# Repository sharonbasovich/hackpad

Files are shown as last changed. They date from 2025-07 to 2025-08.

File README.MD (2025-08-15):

# Sharon's Hackpad
This is a macropad that I made for HackClub's Highway program.

## Features
- 16 Switches (4x4 Matrix)
- 16 Neopixels
- An OLED Screen

## Hackpad


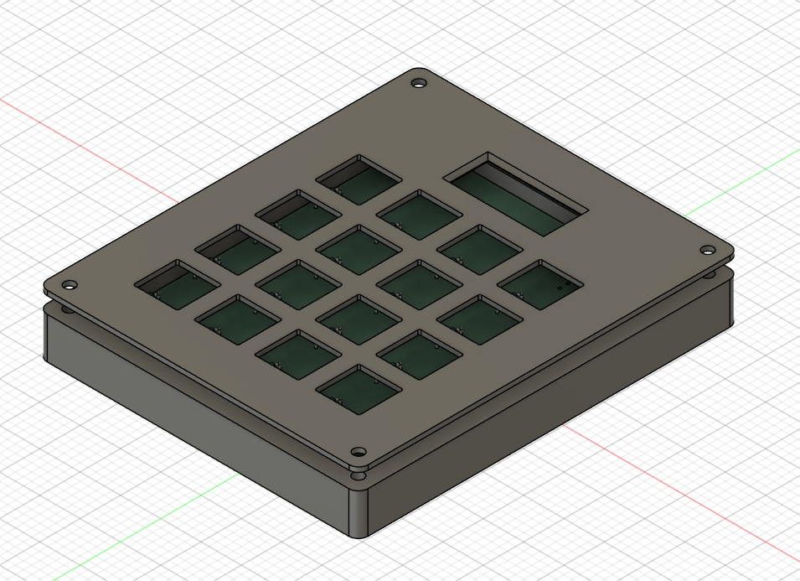
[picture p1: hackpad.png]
Hackpad


## Schematic
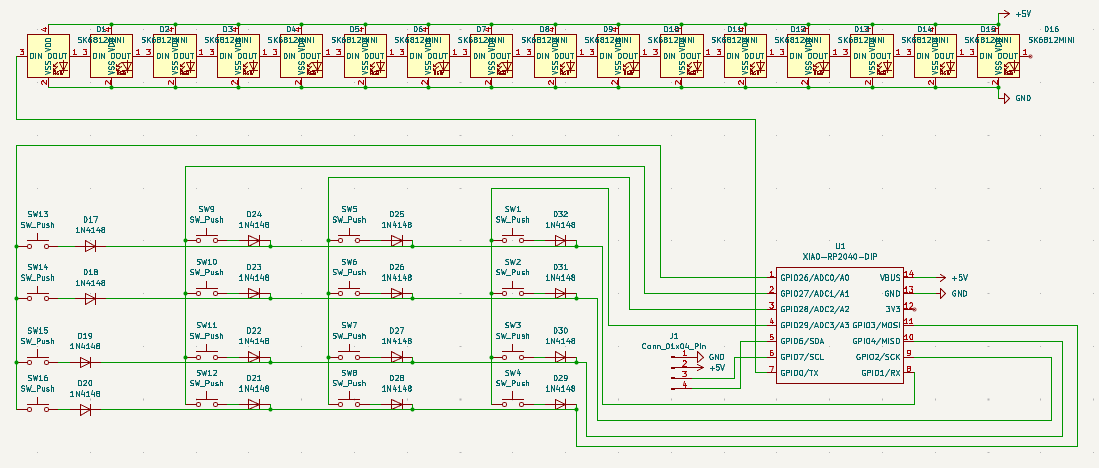
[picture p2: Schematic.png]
Schematic

## PCB
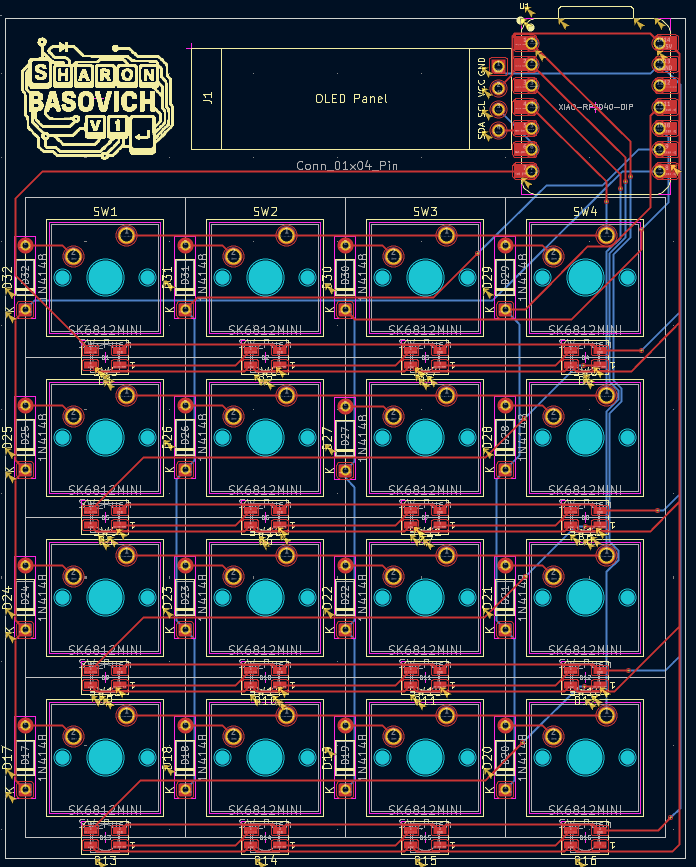
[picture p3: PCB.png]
PCB

## Case
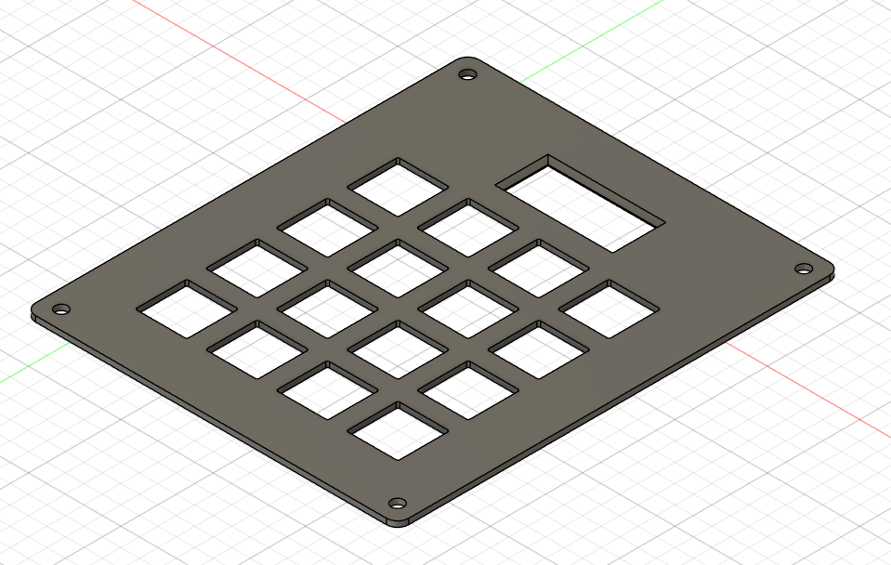
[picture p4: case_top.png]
Case Top

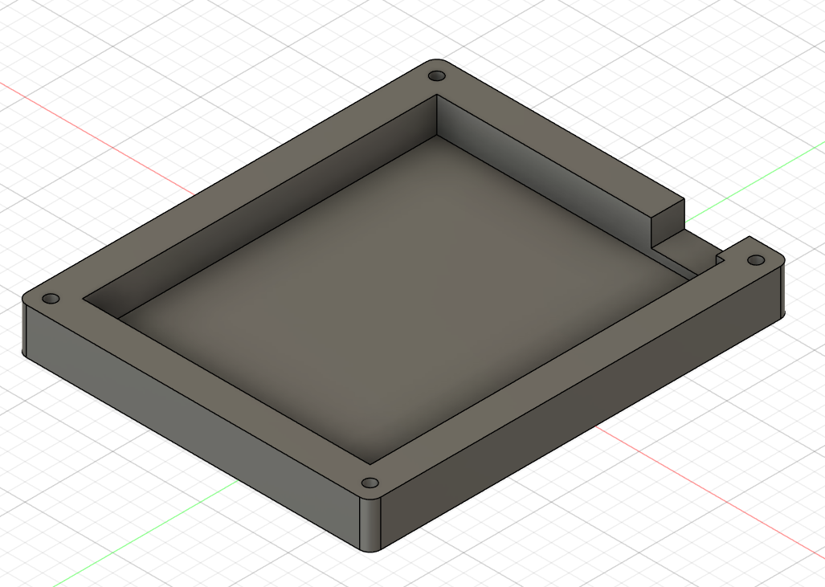
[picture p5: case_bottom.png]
Case Bottom


## BOM
- 16x Cherry MX Switches
- 16x DSA Keycaps
- 16x 1N4148 Diodes
- 1x 0.91" 128x32 OLED Display
- 1x XIAO RP2040
- 1x Case Bottom Piece
- 1x Case Top Piece
- 4x M3x16mm Screws
- 4x M3x5mx4mm Heatset Inserts

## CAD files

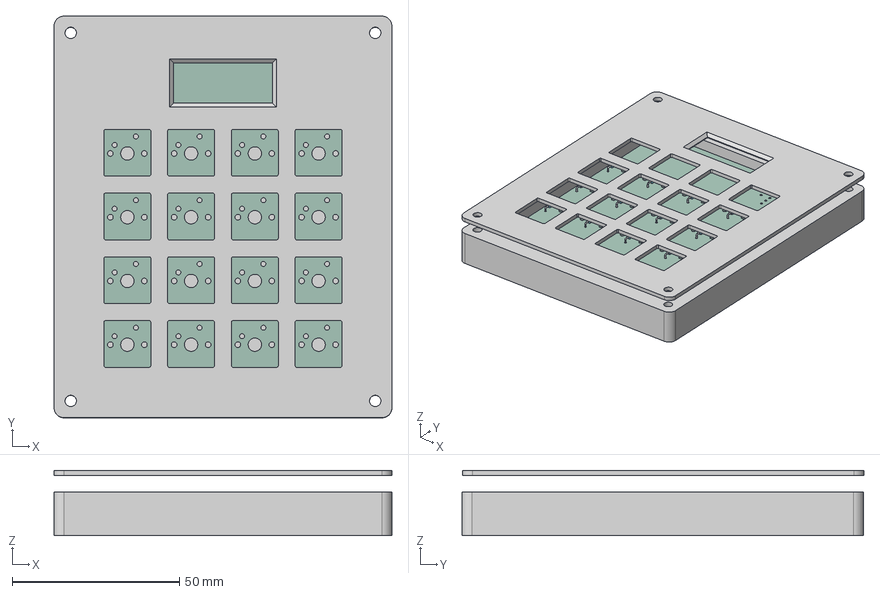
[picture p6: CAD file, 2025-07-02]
CAD/hackpad_assembly.step
101.0 x 120.1 x 19.5 mm
D_DO-35_SOD27_P7.62mm_Horizontal x 16
hackpad_PCB
HackpadTop
Hackpad

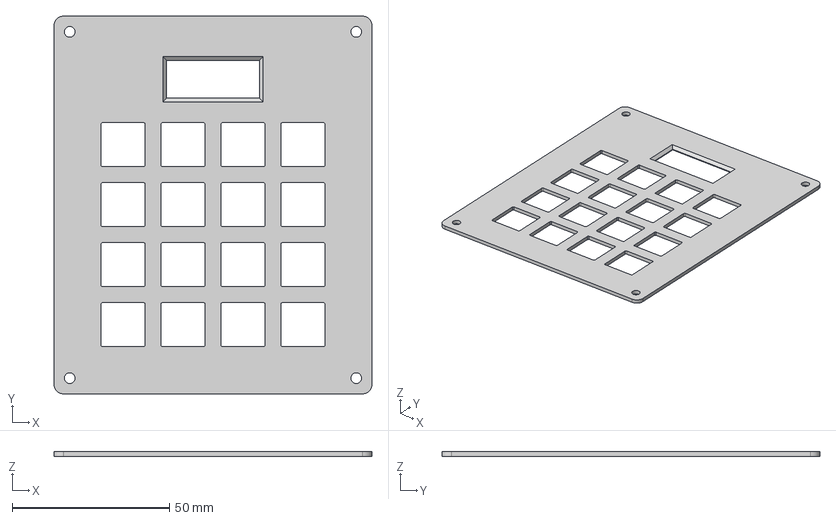
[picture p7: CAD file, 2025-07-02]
Production/hackpad_lid.step
101.0 x 120.0 x 1.50 mm

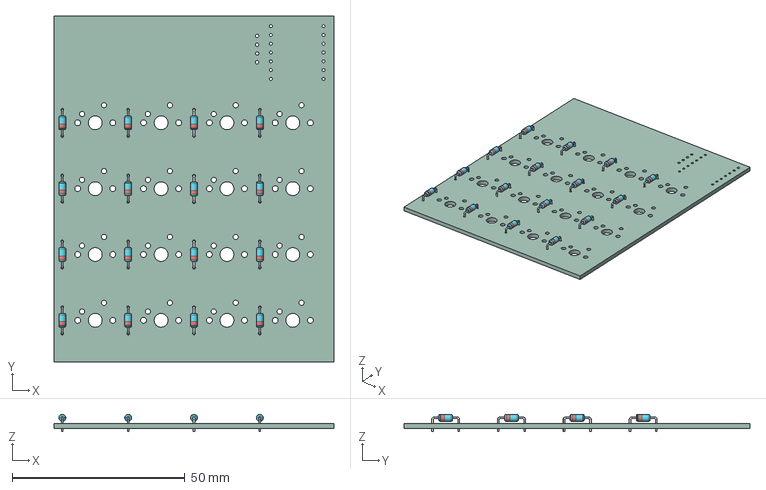
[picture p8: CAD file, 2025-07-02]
CAD/pcb_cad.step
81.0 x 100.0 x 5.01 mm
D_DO-35_SOD27_P7.62mm_Horizontal x 16
hackpad_PCB

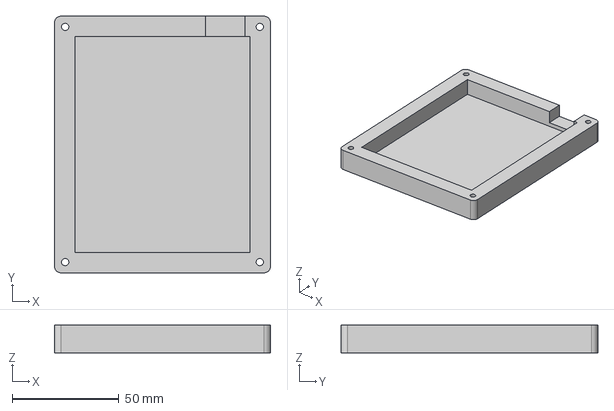
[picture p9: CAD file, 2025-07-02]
Production/hackpad_bottom.step
101.0 x 120.0 x 13.0 mm

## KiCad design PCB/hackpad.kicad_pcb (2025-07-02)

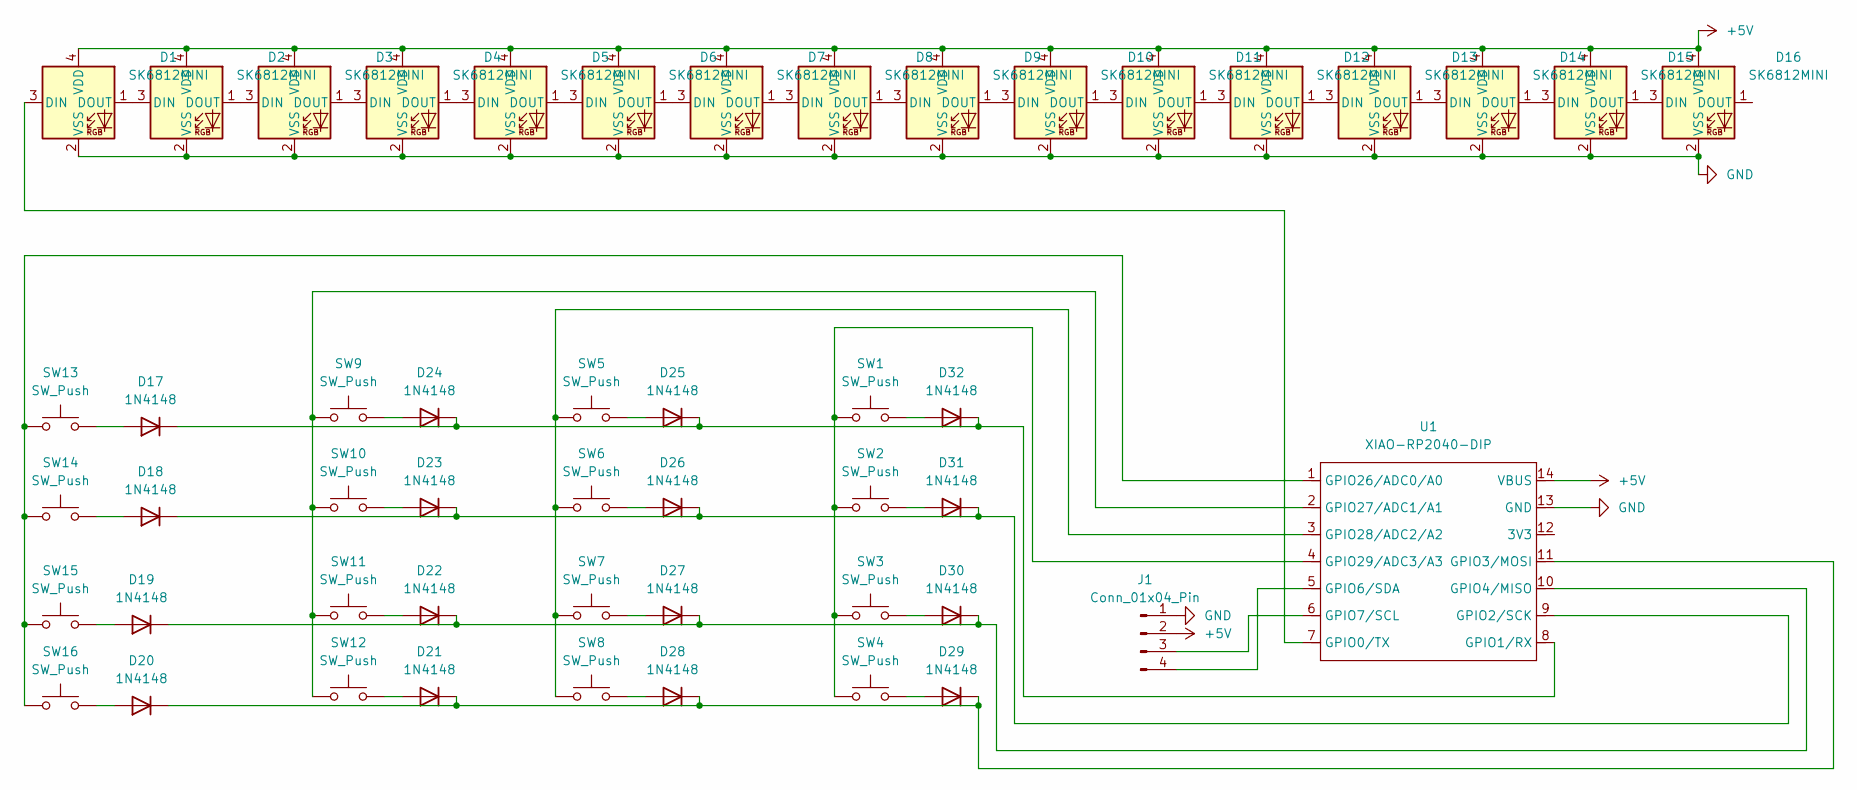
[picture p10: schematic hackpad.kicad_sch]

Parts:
D1, D2, D3, D4, D5, D6, D7, D8, D9, D10, D11, D12, D13, D14, D15, D16: SK6812MINI; LED_SK6812MINI_PLCC4_3.5x3.5mm_P1.75mm
D17, D18, D19, D20, D21, D22, D23, D24, D25, D26, D27, D28, D29, D30, D31, D32: 1N4148; D_DO-35_SOD27_P7.62mm_Horizontal
J1: Conn_01x04_Pin; SSD1306-0.91-OLED-4pin-128x32
SW1, SW2, SW3, SW4, SW5, SW6, SW7, SW8, SW9, SW10, SW11, SW12, SW13, SW14, SW15, SW16: SW_Push; SW_Cherry_MX_1.00u_PCB
U1: XIAO-RP2040-DIP

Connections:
+5V: D1.4 (VDD), D2.4 (VDD), D3.4 (VDD), D4.4 (VDD), D5.4 (VDD), D6.4 (VDD), D7.4 (VDD), D8.4 (VDD), D9.4 (VDD), D10.4 (VDD), D11.4 (VDD), D12.4 (VDD), D13.4 (VDD), D14.4 (VDD), D15.4 (VDD), D16.4 (VDD), J1.2, U1.14 (VBUS)
GND: D1.2 (VSS), D2.2 (VSS), D3.2 (VSS), D4.2 (VSS), D5.2 (VSS), D6.2 (VSS), D7.2 (VSS), D8.2 (VSS), D9.2 (VSS), D10.2 (VSS), D11.2 (VSS), D12.2 (VSS), D13.2 (VSS), D14.2 (VSS), D15.2 (VSS), D16.2 (VSS), J1.1, U1.13 (GND)
unnamed: D1.3 (DIN), U1.7 (GPIO0/TX)
unnamed: D1.1 (DOUT), D2.3 (DIN)
unnamed: D2.1 (DOUT), D3.3 (DIN)
unnamed: D3.1 (DOUT), D4.3 (DIN)
unnamed: D4.1 (DOUT), D5.3 (DIN)
unnamed: D5.1 (DOUT), D6.3 (DIN)
unnamed: D6.1 (DOUT), D7.3 (DIN)
unnamed: D7.1 (DOUT), D8.3 (DIN)
unnamed: D8.1 (DOUT), D9.3 (DIN)
unnamed: D9.1 (DOUT), D10.3 (DIN)
unnamed: D10.1 (DOUT), D11.3 (DIN)
unnamed: D11.1 (DOUT), D12.3 (DIN)
unnamed: D12.1 (DOUT), D13.3 (DIN)
unnamed: D13.1 (DOUT), D14.3 (DIN)
unnamed: D14.1 (DOUT), D15.3 (DIN)
unnamed: D15.1 (DOUT), D16.3 (DIN)
unnamed: D17.2 (A), SW13.2
unnamed: D17.1 (K), D24.1 (K), D25.1 (K), D32.1 (K), U1.8 (GPIO1/RX)
unnamed: D18.2 (A), SW14.2
unnamed: D18.1 (K), D23.1 (K), D26.1 (K), D31.1 (K), U1.9 (GPIO2/SCK)
unnamed: D19.2 (A), SW15.2
unnamed: D19.1 (K), D22.1 (K), D27.1 (K), D30.1 (K), U1.10 (GPIO4/MISO)
unnamed: D20.2 (A), SW16.2
unnamed: D20.1 (K), D21.1 (K), D28.1 (K), D29.1 (K), U1.11 (GPIO3/MOSI)
unnamed: D21.2 (A), SW12.2
unnamed: D22.2 (A), SW11.2
unnamed: D23.2 (A), SW10.2
unnamed: D24.2 (A), SW9.2
unnamed: D25.2 (A), SW5.2
unnamed: D26.2 (A), SW6.2
unnamed: D27.2 (A), SW7.2
unnamed: D28.2 (A), SW8.2
unnamed: D29.2 (A), SW4.2
unnamed: D30.2 (A), SW3.2
unnamed: D31.2 (A), SW2.2
unnamed: D32.2 (A), SW1.2
unnamed: J1.3, U1.6 (GPIO7/SCL)
unnamed: J1.4, U1.5 (GPIO6/SDA)
unnamed: SW13.1, SW14.1, SW15.1, SW16.1, U1.1 (GPIO26/ADC0/A0)
unnamed: SW9.1, SW10.1, SW11.1, SW12.1, U1.2 (GPIO27/ADC1/A1)
unnamed: SW5.1, SW6.1, SW7.1, SW8.1, U1.3 (GPIO28/ADC2/A2)
unnamed: SW1.1, SW2.1, SW3.1, SW4.1, U1.4 (GPIO29/ADC3/A3)

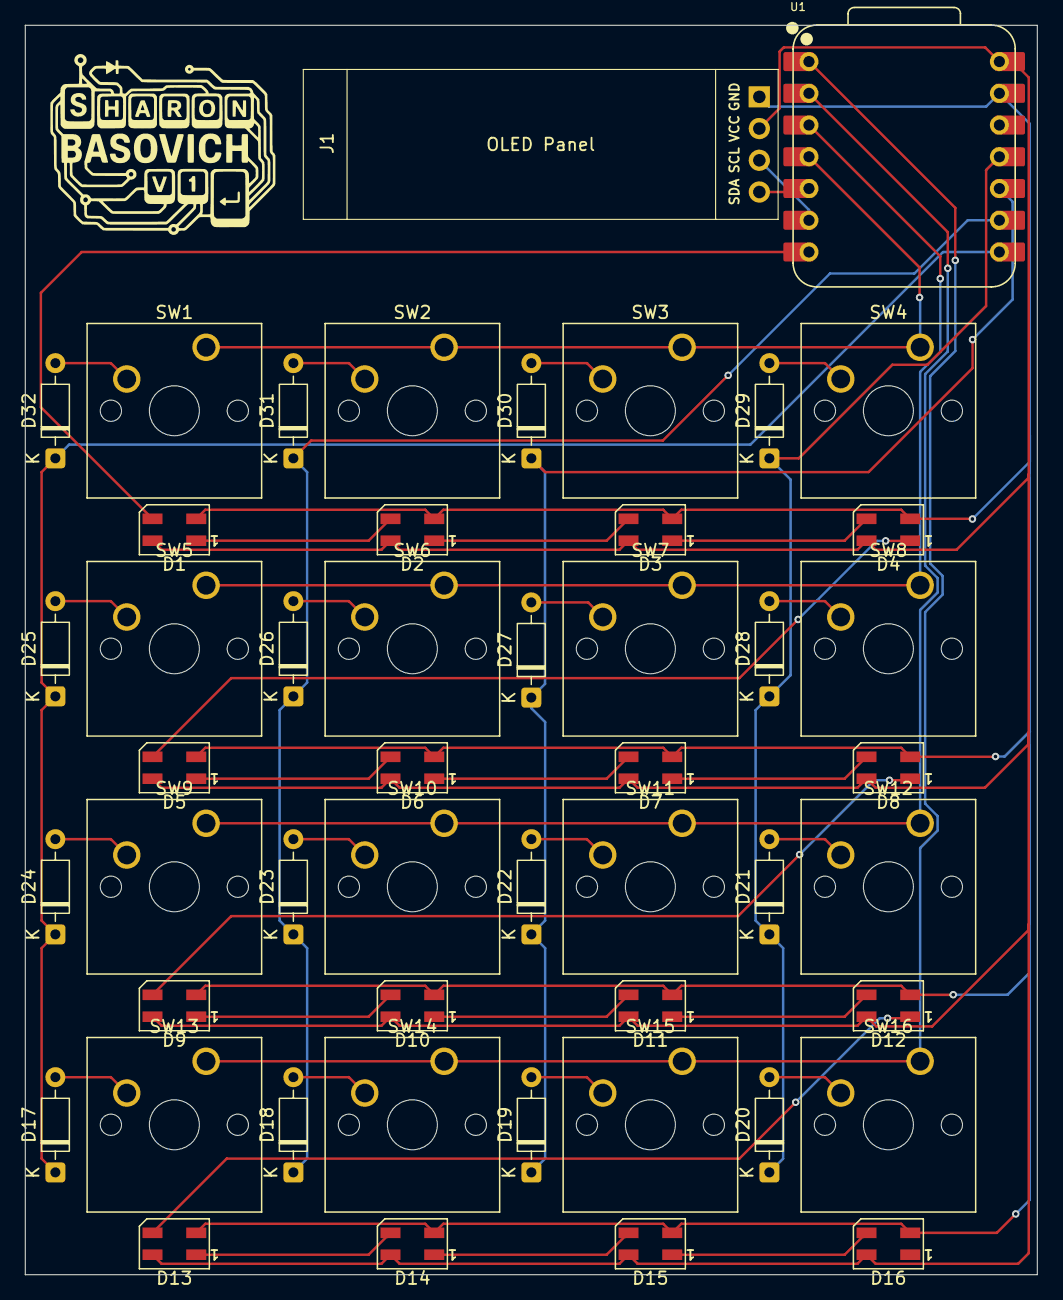
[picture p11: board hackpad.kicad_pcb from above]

Board: 2 copper layers, 81.0 x 100.0 mm, 50 parts (0 on the bottom side), 44 nets.

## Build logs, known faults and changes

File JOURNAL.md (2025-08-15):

# Build Journal
## Time - 2 hours

### Day 1 - 0.5
I printed out my CAD today, and even though switches fit into it, I didn't like how bulky it was. While looking at it in-person I realized how much I can cut down on excess material so I reprinted another version that was way slimmer.


### Day 2 - 0.5
Today the PCB arrived so I started by soldering the diodes. At first, my work was really bad but I realized that if I use pliers to pull the diode in a lot and then bend the extra metal up, they don't move around which makes it a lot easier to solder.


### Day 3 - 1
All that was left was soldering in the switches and oled, which went pretty smoothly. Then I had to test and debug the code. At first it wasn't working but I realized the issue was a missing import was crashing it. Also I kept having an annoying issue where it wouldn't give me write permissions which slowed me down a lot.


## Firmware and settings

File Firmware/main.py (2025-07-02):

import board
import busio

from kmk.kmk_keyboard import KMKKeyboard
from kmk.scanners import DiodeOrientation
from kmk.scanners.keypad import DiodeMatrixScanner
from kmk.keys import KC
from kmk.modules.layers import Layers
from kmk.modules.macros import Macros
from kmk.extensions.rgb import RGB
from kmk.extensions.pegoled import PegOledDisplay

# Main keyboard instance
keyboard = KMKKeyboard()

# Layers and macros
layers = Layers()
macros = Macros()
keyboard.modules.append(layers)
keyboard.modules.append(macros)

# SK6812 MINI-E RGB LEDs on pin D6
led = RGB(
    pixel_pin=board.D6,
    num_pixels=16,
    brightness=0.2,
)
keyboard.extensions.append(led)

# I2C for 0.91" OLED
i2c = busio.I2C(board.SCL, board.SDA)
oled = PegOledDisplay(i2c, width=128, height=32)
keyboard.extensions.append(oled)

# 4×4 key matrix with diodes
keyboard.matrix = DiodeMatrixScanner(
    col_pins=[board.D0, board.D1, board.D2, board.D3],  # columns
    row_pins=[board.D7, board.D8, board.D9, board.D10],  # rows
    diode_orientation=DiodeOrientation.COL2ROW,
)

# 4×4 keymap
keyboard.keymap = [
    [KC.Q, KC.W, KC.E, KC.R],
    [KC.A, KC.S, KC.D, KC.F],
    [KC.Z, KC.X, KC.C, KC.V],
    [KC.KC_1, KC.KC_2, KC.KC_3, KC.KC_4],
]

if __name__ == '__main__':
    keyboard.go()
